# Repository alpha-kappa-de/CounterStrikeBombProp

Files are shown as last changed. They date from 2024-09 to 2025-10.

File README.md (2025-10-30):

# Counter-Strike Bomb Prop Arduino Library
This is the library which handles the behaviour of the Counter-Strike Bomb Prop. Just install this library in your 
Arduino IDE and load the example sketch.

[Here you can see how I build it](https://youtu.be/Wk2TkWnkzZE)
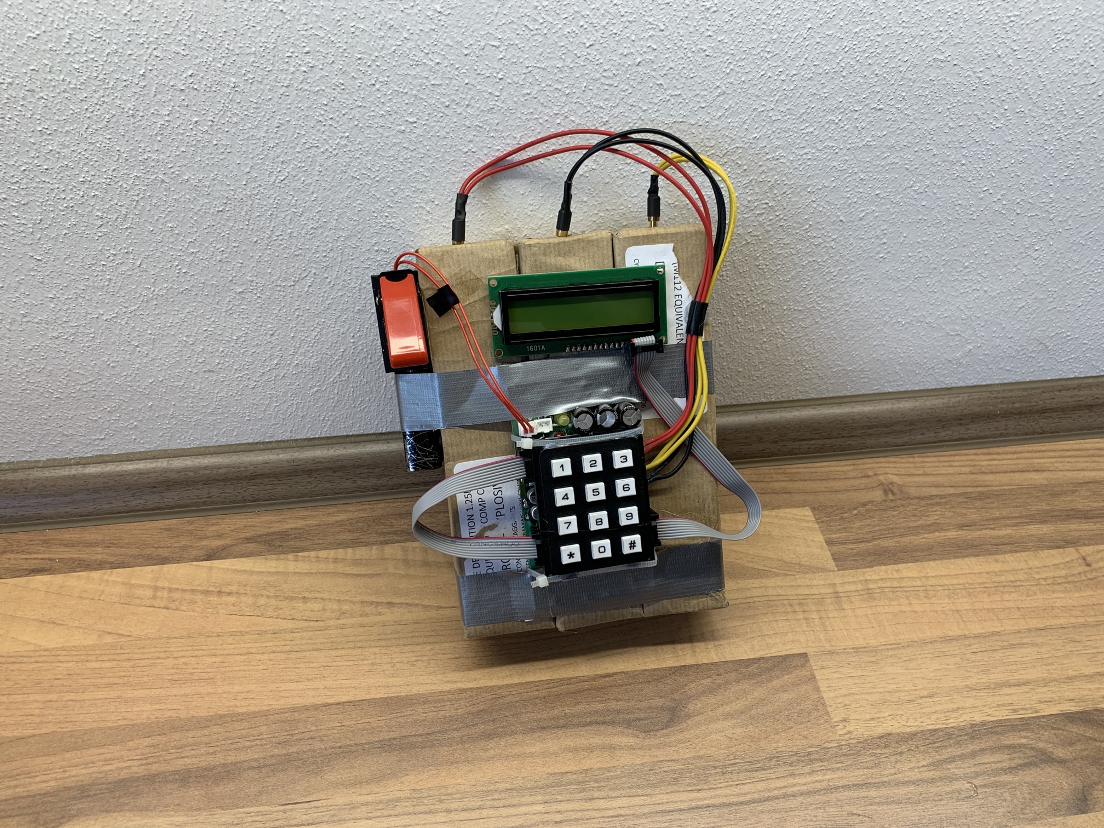
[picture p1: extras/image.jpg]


# Components needed
- 16x1 Display with I2C Module
- Keypad (preferably a 4x3 with white keys)
- Passive buzzer
- DFPlayerMini MP3 module
- Micro SD card
- Speaker
- Red and a yellow LED
- Switch
- (Power button)
- Two 220 Ohm resistors for the LEDs
- 100 Ohm resistor for the buzzer
- 10k Ohm resistor for the switch
- Arduino Nano (or any other Arduino with enough pins)
- A PCB, some wires, an old 9V Battery, cardboard, packing paper, a printer, a 3D printer or a cover for the switch and a lot of patience

# Keypad from Aliexpress
I bought the keypad from aliexpress but couldn't find the pinout so I had to figure it out myself. 
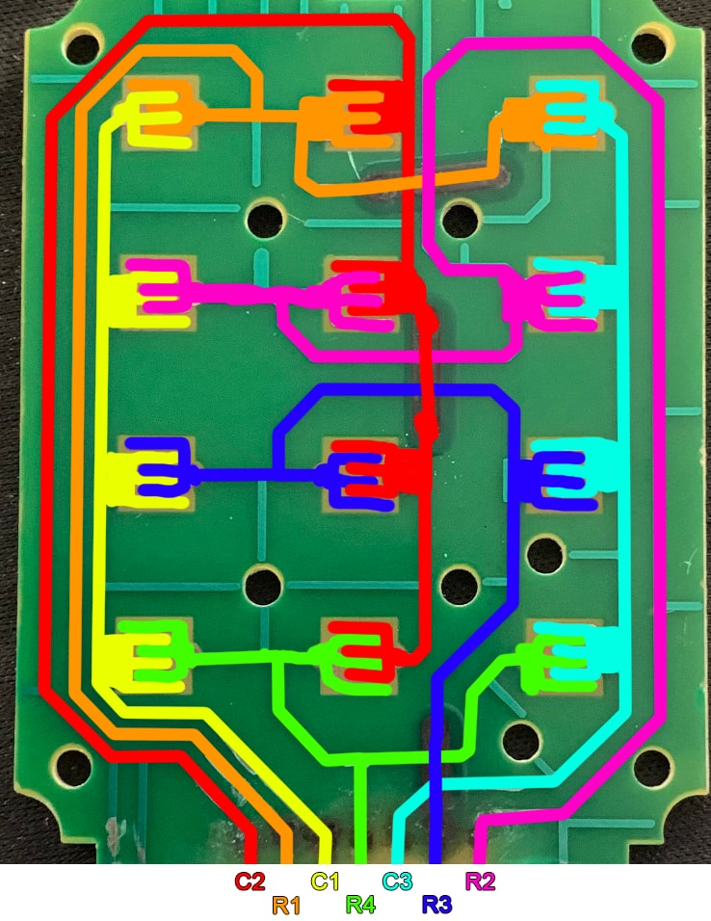
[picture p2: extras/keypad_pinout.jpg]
keypad pinout


| Pin Arduino | Pin keypad | C/R on Keypad |
|---|---|---|
|  6 | 1 | C2 |
|  7 | 2 | R1 |
|  8 | 3 | C1 |
|  9 | 4 | R4 |
| 10 | 5 | C3 |
| 11 | 6 | R3 |
| 12 | 7 | R2 |

# Wiring
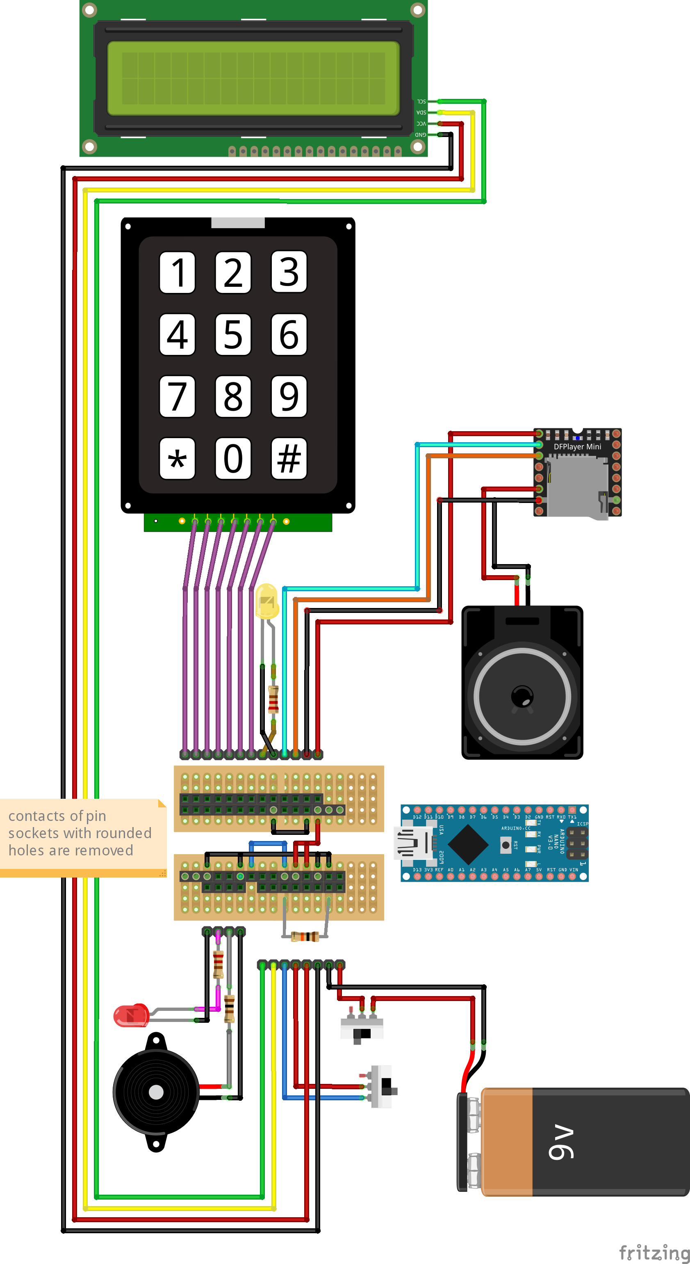
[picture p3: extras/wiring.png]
Wiring


# Audio tracks
I can't upload the audio tracks due to potential copyright reasons. You can extract them from the game yourself. Here is a small tutorial: https://www.youtube.com/watch?v=YFKf5walh84

Here is a list with the description of the audio files:

| Name in .ino | ID in .ino | Description |
|---|---|---|
|  mp3SoundIdInit | 1 | when the switch is toggled |
|  mp3SoundIdRadioBombPlanted | 2 | when code is entered completely |
|  mp3SoundIdRadioBombTickingDown  | 3 | plays some seconds before explosion |
|  mp3SoundIdBeforeExplosion | 4 | high pitch sound right before detonation |
| mp3SoundIdExplosionTerWin | 5 | actual explosion sound |
| mp3SoundIdDisarmStart | 6 | defuse begin sound |
| mp3SoundIdBombDefusedCTWin | 7 | defuse finished sound |
| mp3SoundIdSilence | 8 | silence, which plays between other sounds (it's faster to switch tracks than to start a new one. just put a silent audio track of some minutes here) |

### mp3SoundIdSilence.
Some people asked what the **mp3SoundIdSilence** is for. This is just an audio track with silence for about 10 minutes. I generated it with the tool Audacity. Theoretically you could also put a one hour silence there but I wouldn't do it less than 2-3 minutes.

The mp3SoundIdSilence track is always played between the other sounds. I noticed that the timing is more accurate when doing it like this because the play() Method of DFRobotDFPlayerMini behaves a bit weird here:
When you call DFRobotDFPlayerMini->play(fileNumber) it looks for the file on the SD card and plays it. However if nothing is played at the moment it takes longer to start the playback than if some other sound is played right now and it switches to the new soundfile.

Think of it like this:

This is when you have no silence inbetween:
bad1
You see the free space between the sounds? This is bad and causes delay.

This is when the silence is too short (some seconds), so that it finishes before other sounds are started:
bad2
You see, you still got space between the sounds where no sound is played. That's always bad.

You want to achieve this:
good
When the silence is long enough, it always fills the gaps -> good timing

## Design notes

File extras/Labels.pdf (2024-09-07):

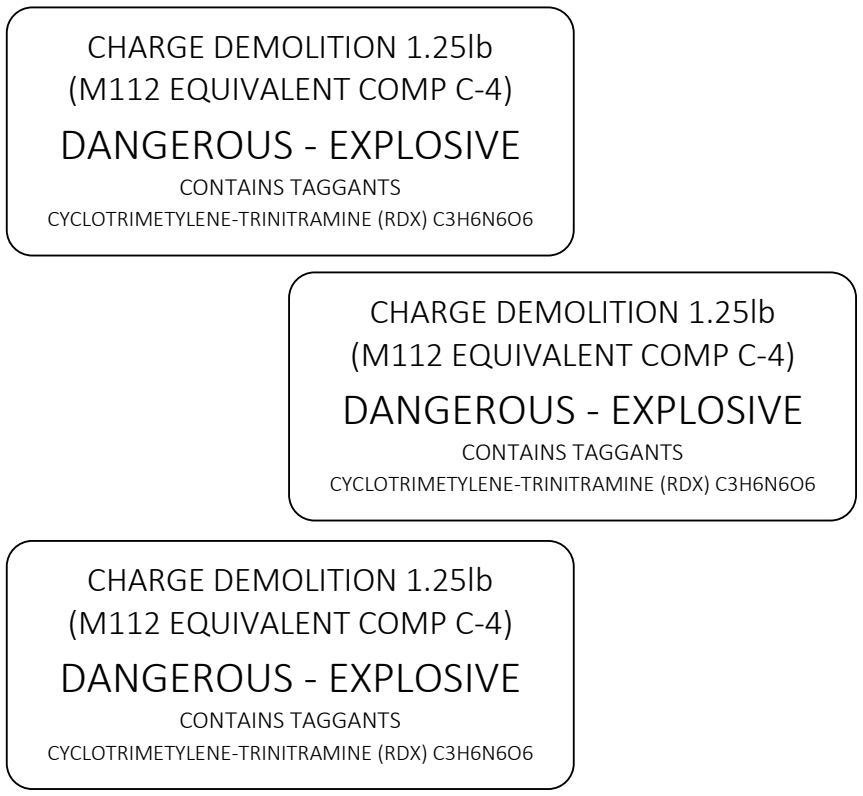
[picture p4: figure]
CHARGE DEMOLITION 1.25lb (M112 EQUIVALENT COMP C-4) DANGEROUS - EXPLOSIVE; CONTAINS TAGGANTS CYCLOTRIMETYLENE-TRINITRAMINE (RDX) C3H6N6O6

*

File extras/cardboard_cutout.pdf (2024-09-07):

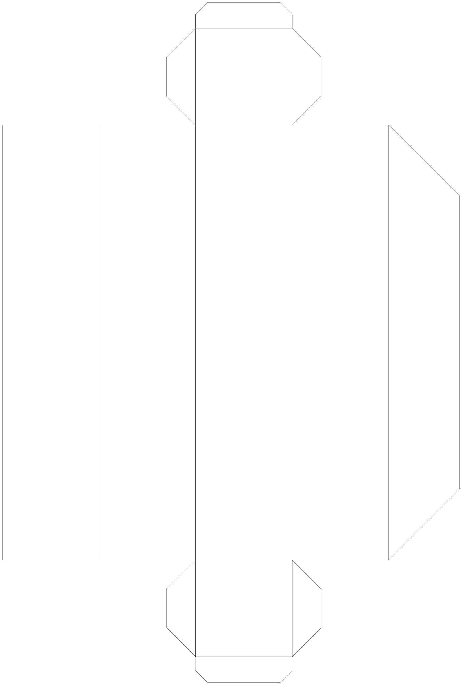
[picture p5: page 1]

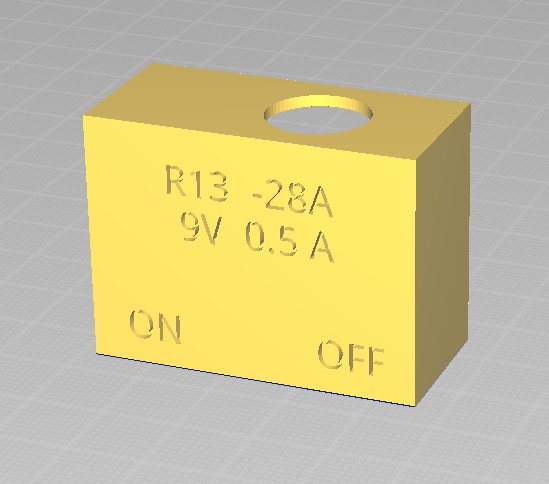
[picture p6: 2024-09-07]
extras/switch_cover.jpg

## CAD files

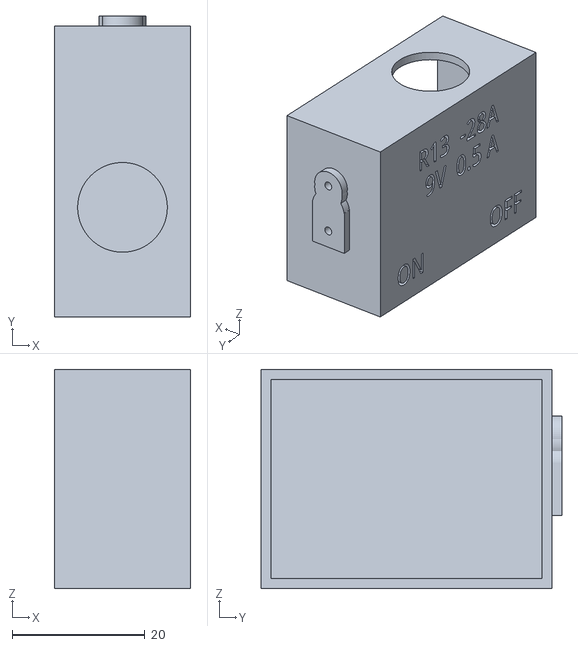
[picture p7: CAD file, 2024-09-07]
extras/CS_Switch_Cover.stl
20.5 x 45.3 x 33.0

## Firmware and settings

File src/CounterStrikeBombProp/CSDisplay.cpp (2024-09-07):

/*
 * MIT License
 *
 * Copyright (c) 2024 alpha-kappa-de
 *
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
 * THE SOFTWARE IS PROVIDED "AS IS", WITHOUT WARRANTY OF ANY KIND, EXPRESS OR
 * IMPLIED, INCLUDING BUT NOT LIMITED TO THE WARRANTIES OF MERCHANTABILITY,
 * FITNESS FOR A PARTICULAR PURPOSE AND NONINFRINGEMENT. IN NO EVENT SHALL
 * THE AUTHORS OR COPYRIGHT HOLDERS BE LIABLE FOR ANY CLAIM, DAMAGES OR OTHER
 * LIABILITY, WHETHER IN AN ACTION OF CONTRACT, TORT OR OTHERWISE, ARISING
 * FROM, OUT OF OR IN CONNECTION WITH THE SOFTWARE OR THE USE OR OTHER
 * DEALINGS IN THE SOFTWARE.
 */

#include "CSDisplay.h"

CSDisplay::CSDisplay() { }

CSDisplay::~CSDisplay() { }

void CSDisplay::setup(byte displayAddress, byte displayCharsPerLine, byte displayLines, bool displayBacklight) {
    this->displayAddress = displayAddress;
    this->displayCharsPerLine = displayCharsPerLine;
    this->displayLines = displayLines;
    this->displayBacklight = displayBacklight;

    this->lcd = new LiquidCrystal_I2C(this->displayAddress, this->displayCharsPerLine, this->displayLines);
    this->bombCode = new char[BOMB_CODE_LENGTH];
    for (int i = 0; i < BOMB_CODE_LENGTH; i++) {
        this->bombCode[i] = '*';
    }

    this->currentAnimation = ANIMATION_LCD_NONE;
    this->currentAnimationState = 0;
    this->animationPlantedCountUp = true;
    this->hasDefuseKit = false;
    this->lastTime = 0;
    this->currentDefusingCharIndex = 0;
    this->defuseBeginTime = 0;
    this->DefusedAnimationShowChars = false;

    this->lcd->init();

    if (this->displayBacklight) {
        this->activateBacklight();
    } else {
        this->deactivateBacklight();
    }
    this->clearDisplay();

    this->lcd->createChar(FLIPPED_CHAR_1, this->flipped_1);
    this->lcd->createChar(FLIPPED_CHAR_2, this->flipped_2);
    this->lcd->createChar(FLIPPED_CHAR_3, this->flipped_3);
    this->lcd->createChar(FLIPPED_CHAR_4, this->flipped_4);
    this->lcd->createChar(FLIPPED_CHAR_5, this->flipped_5);
    this->lcd->createChar(FLIPPED_CHAR_7, this->flipped_7);

    #if defined(SERIAL_DEBUG)
        DebugPrintln(PREFIX_DISPLAY, STR_INITIALIZED);
    #endif
}


void CSDisplay::activateBacklight() {
    #if defined(SERIAL_DEBUG)
        DebugPrintln(PREFIX_DISPLAY, "Activating BL");
    #endif
    this->lcd->backlight();
}

void CSDisplay::deactivateBacklight() {
    #if defined(SERIAL_DEBUG)
        DebugPrintln(PREFIX_DISPLAY, "Deactivating BL");
    #endif
    this->lcd->noBacklight();
}

void CSDisplay::clearDisplay() {
    #if defined(SERIAL_DEBUG)
        DebugPrintln(PREFIX_DISPLAY, "Clearing");
    #endif
    this->lcd->clear();
}

void CSDisplay::startDisplayBombCodeAnimation() {
    #if defined(SERIAL_DEBUG)
        DebugPrintln(PREFIX_DISPLAY, "Start bomb code anim");
    #endif
    this->currentAnimation = ANIMATION_LCD_BOMB_CODE;
    this->currentAnimationState = 0;
    this->clearBombCode();
    this->lastTime = millis();
}

void CSDisplay::startPlantedAnimation() {
    #if defined(SERIAL_DEBUG)
        DebugPrintln(PREFIX_DISPLAY, "Start planted anim");
    #endif
    this->currentAnimation = ANIMATION_LCD_PLANTED;
    this->currentAnimationState = 0;
    this->lastTime = millis();
}

void CSDisplay::startDefusingAnimation(bool hasDefuseKit) {
    #if defined(SERIAL_DEBUG)
        DebugPrint(PREFIX_DISPLAY, "Start bomb defuse anim (defuse kit: ");
        Serial.print(hasDefuseKit ? "YES" : "NO");
        Serial.println(")");
    #endif
    this->currentAnimation = ANIMATION_LCD_DEFUSING;
    this->currentAnimationState = 0;
    this->lastTime = millis();
    this->hasDefuseKit = hasDefuseKit;
}

void CSDisplay::stopAnimation() {
    #if defined(SERIAL_DEBUG)
        DebugPrintln(PREFIX_DISPLAY, "Stopping anim");
    #endif

    this->clearDisplay();
    this->currentAnimation = ANIMATION_LCD_NONE;
    this->currentAnimationState = 0;
    this->animationPlantedCountUp = true;
    this->hasDefuseKit = false;
    this->lastTime = 0;
    this->currentDefusingCharIndex = 0;
    this->defuseBeginTime = 0;
    this->DefusedAnimationShowChars = false;
}

void CSDisplay::tick() {
    switch (this->currentAnimation) {
        case ANIMATION_LCD_BOMB_CODE:
            this->tickBombCodeAnimation();
            break;
        case ANIMATION_LCD_PLANTED:
            this->tickPlantedAnimation();
            break;
        case ANIMATION_LCD_DEFUSING:
            this->tickDefusingAnimation();
            break;
        default:
            break;
    }
}

bool CSDisplay::addToBombCode(char c) {
    // shift all characters to the left
    for (int i = 0; i < BOMB_CODE_LENGTH - 1; i++) {
        this->bombCode[i] = this->bombCode[i + 1];
    }
    this->bombCode[BOMB_CODE_LENGTH - 1] = c;
    #if defined(SERIAL_DEBUG)
        DebugPrint(PREFIX_DISPLAY, "Bomb code: ");
        for (int i = 0; i < BOMB_CODE_LENGTH; i++) {
             Serial.print(this->bombCode[i]);
        }
        Serial.println();
    #endif

    if (this->bombCode[0] != '*') {
        return true;
    }
    return false;
}

void CSDisplay::clearBombCode() {
    for (int i = 0; i < BOMB_CODE_LENGTH; i++) {
        this->bombCode[i] = '*';
    }
    #if defined(SERIAL_DEBUG)
        DebugPrint(PREFIX_DISPLAY, "Bomb code: ");
        for (int i = 0; i < BOMB_CODE_LENGTH; i++) {
            Serial.print(this->bombCode[i]);
        }
        Serial.println();
    #endif
}

void CSDisplay::tickBombCodeAnimation() {
    this->lcd->setCursor(0, 1);
    char currentChar;
    for (int i = BOMB_CODE_LENGTH - 1; i >= 0; i--) {
        this->printCharToDisplay(this->bombCode[i]);
    }
}

void CSDisplay::tickPlantedAnimation() {
    // use the currentAnimationState to determine the position of the '*'
    this->lcd->setCursor(this->currentAnimationState, 1);
    this->lcd->print('*');

    // if the time has passed
    if ((this->lastTime + PLANTED_ANIM_DURATION_PER_STATE) <= millis()) {
        this->lastTime = millis();

        // remove the '*' from the previous position
        this->lcd->setCursor(this->currentAnimationState, 1);
        this->lcd->print(' ');

        // update the currentAnimationState / position of the '*'
        if (this->animationPlantedCountUp) {
            this->currentAnimationState++;
        } else {
            this->currentAnimationState--;
        }

        // if the '*' has reached the end of the line, change the direction for the next tick
        if (this->currentAnimationState == this->displayCharsPerLine - 1) {
            this->animationPlantedCountUp = false;
        } else if (this->currentAnimationState == 0) {
            this->animationPlantedCountUp = true;
        }
    }
}
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

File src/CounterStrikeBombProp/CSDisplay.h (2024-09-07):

/*
 * MIT License
 *
 * Copyright (c) 2024 alpha-kappa-de
 *
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
 * THE SOFTWARE IS PROVIDED "AS IS", WITHOUT WARRANTY OF ANY KIND, EXPRESS OR
 * IMPLIED, INCLUDING BUT NOT LIMITED TO THE WARRANTIES OF MERCHANTABILITY,
 * FITNESS FOR A PARTICULAR PURPOSE AND NONINFRINGEMENT. IN NO EVENT SHALL
 * THE AUTHORS OR COPYRIGHT HOLDERS BE LIABLE FOR ANY CLAIM, DAMAGES OR OTHER
 * LIABILITY, WHETHER IN AN ACTION OF CONTRACT, TORT OR OTHERWISE, ARISING
 * FROM, OUT OF OR IN CONNECTION WITH THE SOFTWARE OR THE USE OR OTHER
 * DEALINGS IN THE SOFTWARE.
 */

#ifndef COUNTERSTRIKEBOMBPROP_CSDISPLAY_H
#define COUNTERSTRIKEBOMBPROP_CSDISPLAY_H

#include "../CounterStrikeBombProp.h"
#include <LiquidCrystal_I2C.h>

#define PLANTED_ANIM_DURATION_PER_STATE 75
#define DEFUSING_CHAR_ANIM_DURATION 100
#define DEFUSING_ANIM_DURATION 500
#define BOMB_CODE_LENGTH 7
#define FLIPPED_CHAR_1 0
#define FLIPPED_CHAR_2 1
#define FLIPPED_CHAR_3 2
#define FLIPPED_CHAR_4 3
#define FLIPPED_CHAR_5 4
#define FLIPPED_CHAR_7 5

enum AnimationLCD {
    ANIMATION_LCD_NONE,
    ANIMATION_LCD_BOMB_CODE,
    ANIMATION_LCD_PLANTED,
    ANIMATION_LCD_DEFUSING
};

/**
 * @brief This class is responsible for managing the display of the Counter Strike Bomb Prop. It has some custom characters
 *        of the number chars, because the display is flipped. <br><br>
 * @details There are three animations, which can be displayed <br>
 *          - <b>Bomb code input:</b> The bomb code is being entered and the characters that are not entered yet are displayed as * <br>
 *          - <b>Planted:</b> The bomb is planted and the * character is moving from left to right <br>
 *          - <b>Defusing:</b> The bomb is being defused and the characters of the bomb code are being revealed one after another <br><br>
 *          Before using an object of this class, make sure to call the setup() method. <br><br>
 *          <h1>Methods</h1> <br>
 *          <b>setup():</b> Setup the keypad with the given parameters. <br><br>
 *          <b>tick():</b> If a button is pressed, it will be added to the queue (if allowedToEnqueue is true). <br><br>
 *          <b>getButton():</b> Get the next button that was pressed from the queue. <br><br>
 *          <b>hasButton():</b> Check if there is a button in the queue. <br><br>
 *          <b>resetQueue():</b> Reset the queue so it is empty. <br><br>
 *          <b>setAllowedToEnqueue():</b> Set the flag that indicates if it's allowed to enqueue a key or not. <br><br>
 *          <b>isAnyKeyPressed():</b> Checks if there is any key pressed or held down. <br><br>
 * @see LiquidCrystal_I2C
 */
class CSDisplay {
private:
    byte displayAddress;                // I2C address of the display
    byte displayCharsPerLine;           // Number of characters per line
    byte displayLines;                  // Number of lines
    bool displayBacklight;              // Backlight state
    char* bombCode;                     // Current bomb code

    // some custom characters (because the display is flipped)
    uint8_t flipped_1[8] = { 0x0E, 0x04, 0x04, 0x04, 0x04, 0x06, 0x04, 0x00 };
    uint8_t flipped_2[8] = { 0x1F, 0x02, 0x04, 0x08, 0x10, 0x11, 0x0E, 0x00 };
    uint8_t flipped_3[8] = { 0x0E, 0x11, 0x10, 0x08, 0x04, 0x08, 0x1F, 0x00 };
    uint8_t flipped_4[8] = { 0x08, 0x08, 0x1F, 0x09, 0x0A, 0x0C, 0x08, 0x00 };
    uint8_t flipped_5[8] = { 0x0E, 0x11, 0x10, 0x10, 0x0F, 0x01, 0x1F, 0x00 };
    uint8_t flipped_7[8] = { 0x02, 0x02, 0x02, 0x04, 0x08, 0x10, 0x1F, 0x00 };

    LiquidCrystal_I2C *lcd = nullptr;   // LiquidCrystal_I2C object for the display

    AnimationLCD currentAnimation;      // Current animation that should be displayed
    byte currentAnimationState;         // Current animation state
    bool animationPlantedCountUp;       // If the planted animation should count up or down (position of the * character)
    bool hasDefuseKit;                  // If the defuser has a defuse kit (fast or slow defuse animation)
    unsigned long lastTime;             // Last time the animation was updated
    unsigned long defuseBeginTime;      // Time the defusing animation started
    int currentDefusingCharIndex;       // Current character index of the defusing animation
    bool DefusedAnimationShowChars;     // If the defusing animation should show the actual characters or *******

    /**
     * @brief Play one tick of the bomb code animation
     */
    void tickBombCodeAnimation();

    /**
     * @brief Play one tick of the planted animation
     */
    void tickPlantedAnimation();

    /**
     * @brief Play one tick of the defusing animation
     */
    void tickDefusingAnimation();

    /**
     * @brief Print a character to the display at the current position. This function prints the character upside down,
     * but only if the character is one of these: 1, 2, 3, 4, 5, 6, 7, 8, 9, 0, *
     *
     * @param c The character to print
     */
    void printCharToDisplay(char c);

public:
    /**
     * @brief Constructor for the CSDisplay class.
     */
    CSDisplay();

    /**
     * @brief Destructor for the CSDisplay class.
     */
    ~CSDisplay();

    /**
     * @brief Setup the display with the given parameters
     *
     * @param displayAddress The I2C address of the display
     * @param displayCharsPerLine The number of characters per line
     * @param displayLines The number of lines
     * @param displayBacklight The backlight state
     */
    void setup(byte displayAddress, byte displayCharsPerLine, byte displayLines, bool displayBacklight);

    /**
     * @brief Activate the backlight of the display
     */
    void activateBacklight();

    /**
     * @brief Deactivate the backlight of the display
     */
    void deactivateBacklight();

    /**
     * @brief Clear the display (doesn't reset the cursor)
     */
    void clearDisplay();

    /**
     * @brief Set the current animation to display the bomb code while it is being entered (not entered characters will be displayed as *)
     */
    void startDisplayBombCodeAnimation();

    /**
     * @brief Set the current animation to the planted animation (moving * character)
     */
    void startPlantedAnimation();

    /**
     * @brief Set the current animation to the defusing animation (display showing ******* and one after another the
     * characters of the bomb code will be revealed while the current character is showing a random character)
     */
    void startDefusingAnimation(bool hasDefuseKit);

    /**
     * @brief Stop the current animation
     */
    void stopAnimation();

    /**
     * @brief Play a tick of the current animation
     */
    void tick();

    /**
     * @brief Add a character to the bomb code
     *
     * @param c The character to add
     * @return True if the bomb code is complete, false otherwise
     */
    bool addToBombCode(char c);

    /**
     * @brief Clear the bomb code
     */
    void clearBombCode();
};
#endif
